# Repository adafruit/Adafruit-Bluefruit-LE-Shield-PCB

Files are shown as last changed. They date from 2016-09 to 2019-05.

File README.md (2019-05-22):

## Adafruit Bluefruit LE Shield PCB
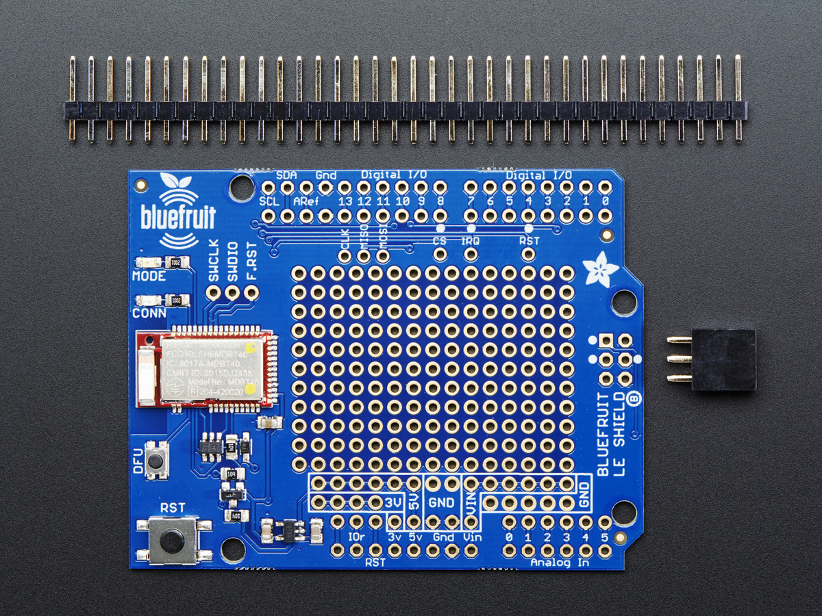
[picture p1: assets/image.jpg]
<a href="http://www.adafruit.com/products/2746"><br/>
Click here to purchase one from the Adafruit shop</a>

Would you like to add powerful and easy-to-use Bluetooth Low Energy to your robot, art or other electronics project? Heck yeah! With BLE now included in modern smart phones and tablets, its fun to add wireless connectivity. So what you really need is the new Adafruit Bluefruit LE Shield for Arduino!

The Bluefruit LE Shield makes it easy to add Bluetooth Low Energy connectivity to your Arduino or compatible.  Solder in the included headers and plug right in. It connects to your Arduino or other microcontroller using the hardware SPI interface (MISO, MOSI, SCK) plus a chip select line (default D8), interrupt line (default D7) and reset (default D4). You can rearrange any and all the pins if you'd like, by cutting the jumpers underneath, and soldering jumper wires to your desired pins.

PCB files for the Adafruit Bluefruit LE Shield. The format is EagleCAD schematic and board layout
- https://www.adafruit.com/product/2746

### License

Adafruit invests time and resources providing this open source design, please support Adafruit and open-source hardware by purchasing products from [Adafruit](https://www.adafruit.com)!

All text above must be included in any redistribution

Designed by Limor Fried/Ladyada for Adafruit Industries.
Creative Commons Attribution/Share-Alike, all text above must be included in any redistribution. 
See license.txt for additional information.

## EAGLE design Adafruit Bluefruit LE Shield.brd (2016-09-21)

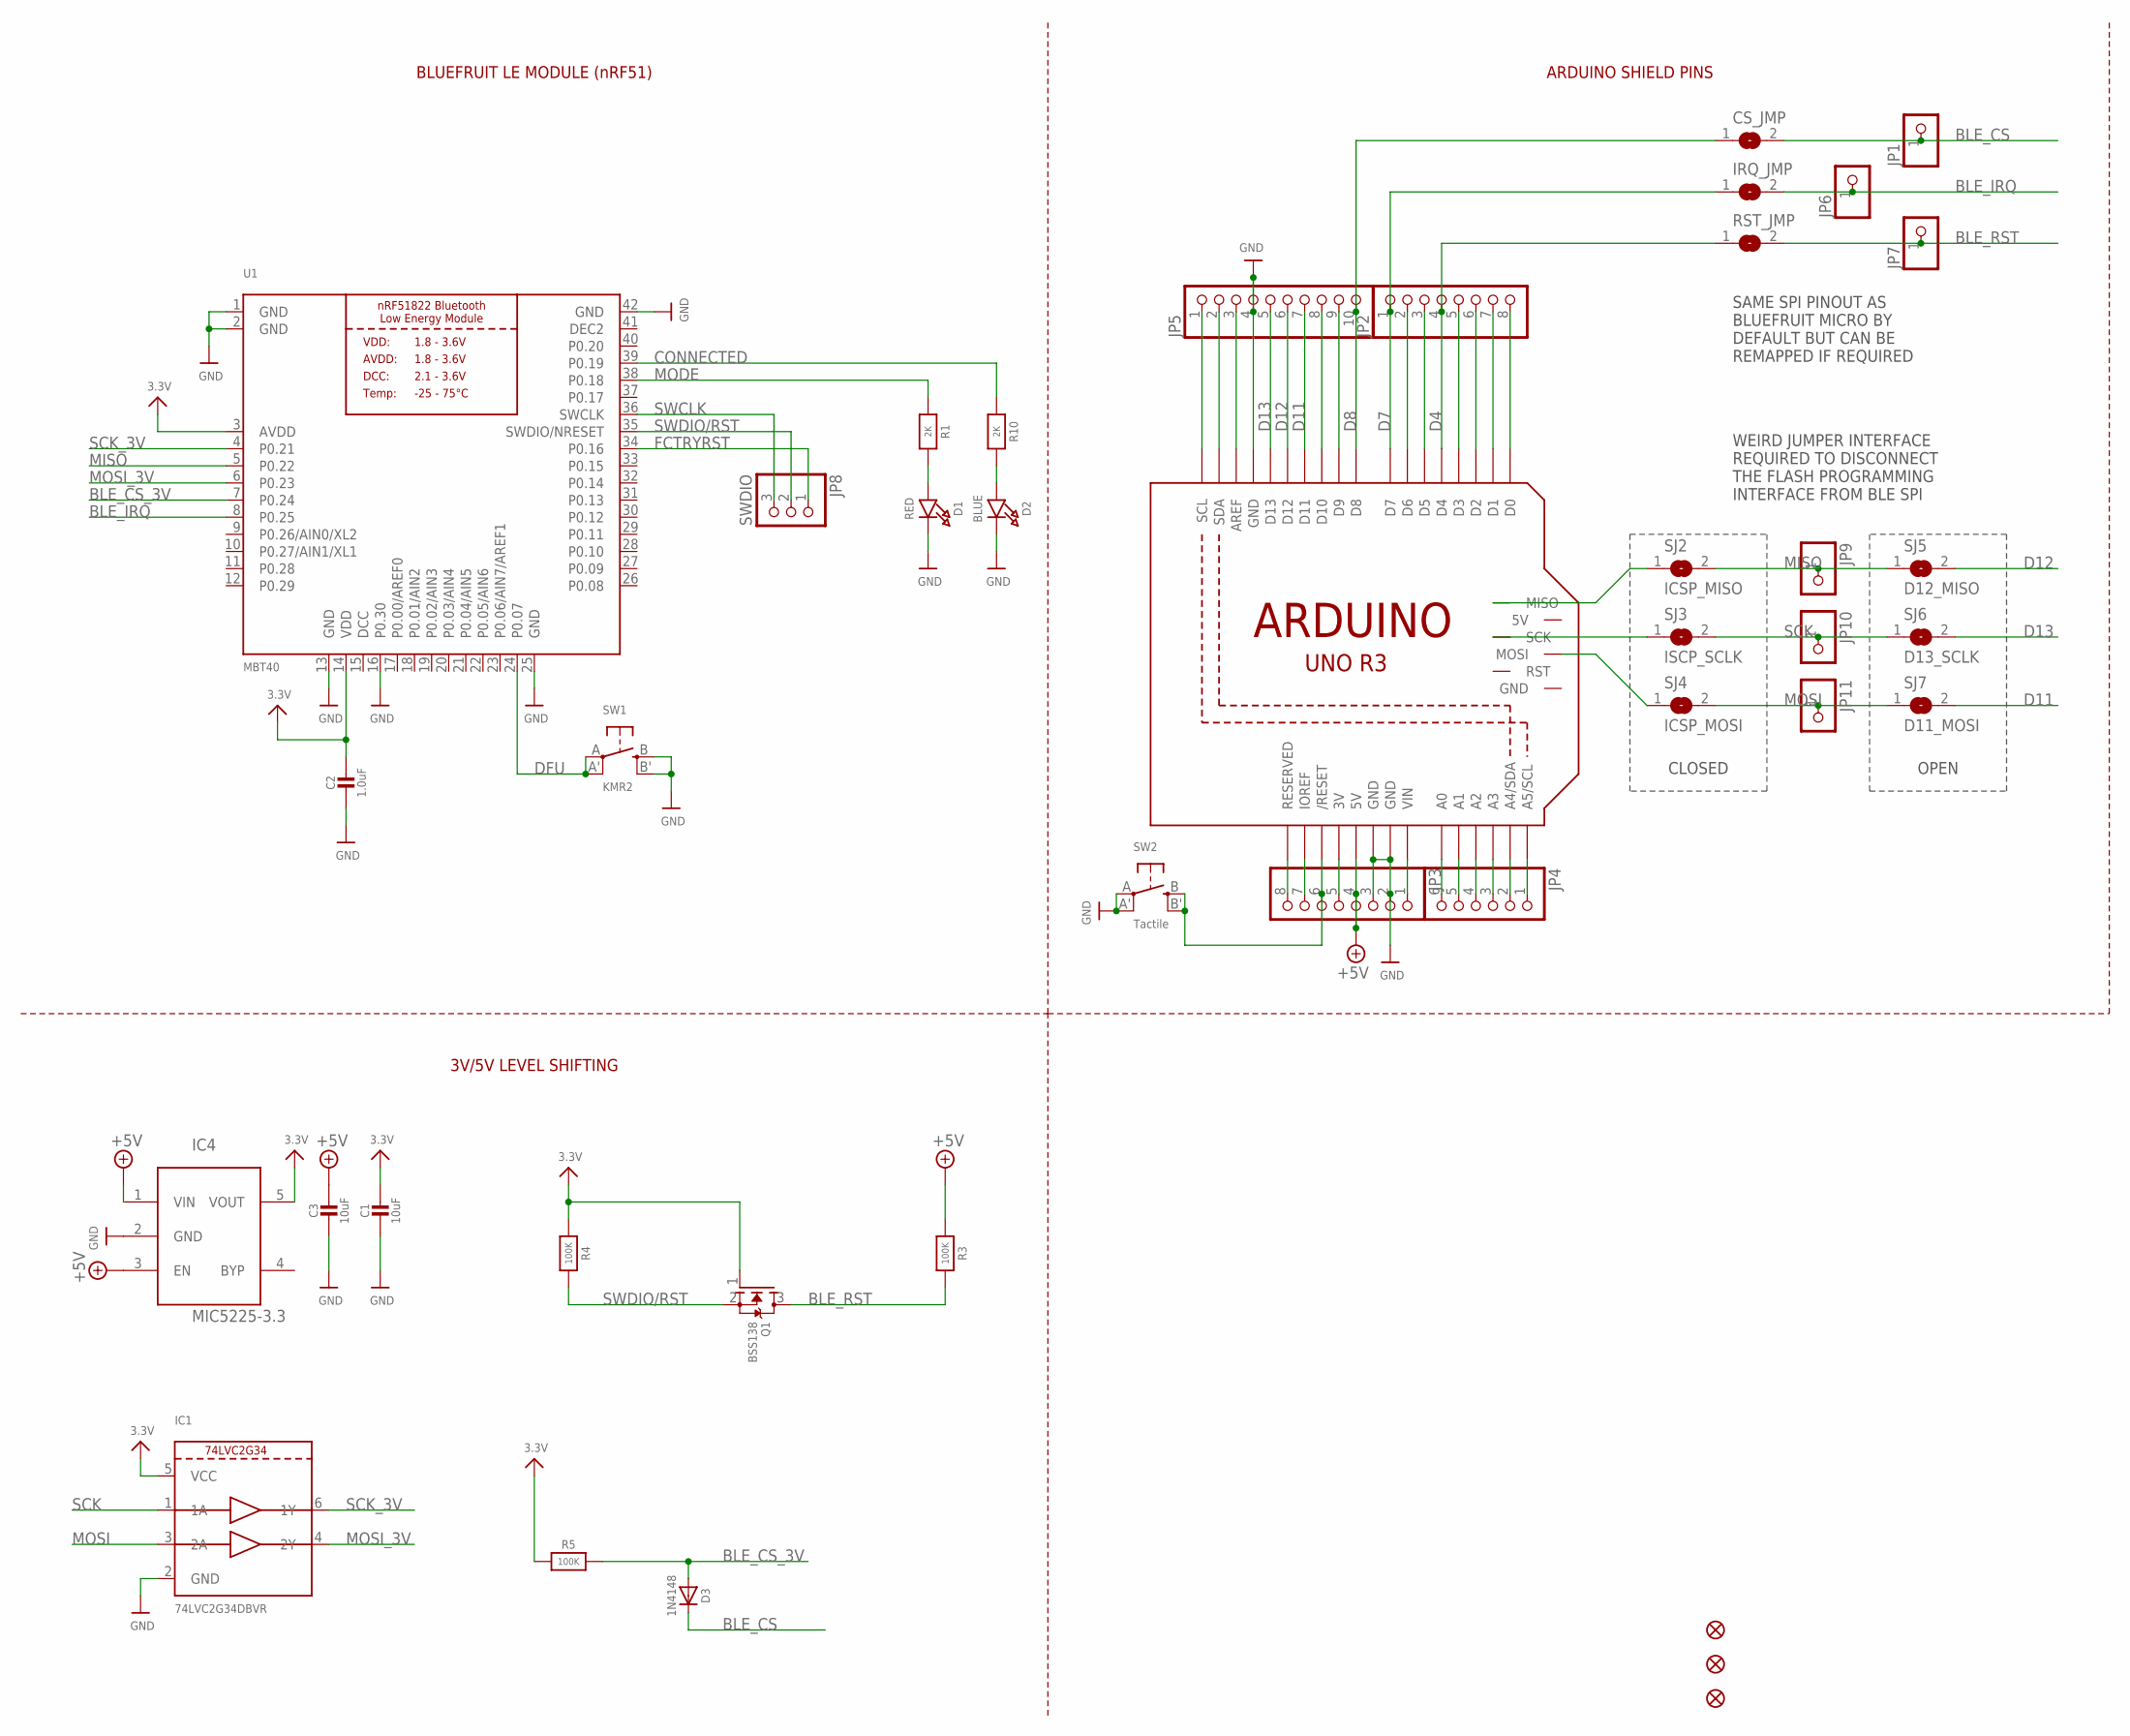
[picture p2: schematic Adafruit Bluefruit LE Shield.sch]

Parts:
C1, C3: 10uF; 0805-NO
C2: 1.0uF; 0805-NO
CS_JMP: SOLDERJUMPERCLOSED; SOLDERJUMPER_CLOSEDWIRE
D1: RED; CHIPLED_0805_NOOUTLINE
D2: BLUE; CHIPLED_0805_NOOUTLINE
D3: 1N4148; SOD-323
FID1, FID2, FID3: FIDUCIAL""; FIDUCIAL_1MM
IC1: 74LVC2G34DBVR; SOT23-6
IC4: MIC5225-3.3; SOT23-5L
IRQ_JMP: SOLDERJUMPERCLOSED; SOLDERJUMPER_CLOSEDWIRE
JP1, JP6, JP7, JP9, JP10, JP11: HEADER-1X1ROUND; 1X01_ROUND
JP2, JP3: HEADER-1X870MIL; 1X08_ROUND_70
JP4: HEADER-1X670MIL; 1X06_ROUND_70
JP5: HEADER-1X1070MIL; 1X10_ROUND70
JP8: SWDIO; 1X03_ROUND_76
M1: ARDUINO_R3_ICSP_NODIM; ARDUINOR3_ICSP_NODIM
Q1: BSS138; SOT23-WIDE
R1, R10: 2K; 0805-NO
R3, R4, R5: 100K; 0805-NO
RST_JMP: SOLDERJUMPERCLOSED; SOLDERJUMPER_CLOSEDWIRE
SJ2: ICSP_MISO; SOLDERJUMPER_CLOSEDWIRE
SJ3: ISCP_SCLK; SOLDERJUMPER_CLOSEDWIRE
SJ4: ICSP_MOSI; SOLDERJUMPER_CLOSEDWIRE
SJ5: D12_MISO; SOLDERJUMPER_REFLOW_NOPASTE
SJ6: D13_SCLK; SOLDERJUMPER_REFLOW_NOPASTE
SJ7: D11_MOSI; SOLDERJUMPER_REFLOW_NOPASTE
SW1: KMR2; BTN_KMR2_4.6X2.8
SW2: Tactile; EVQ-Q2
U1: MBT40; BLE_MODULE_RAYTAC_MDBT40

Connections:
3.3V: C1.1, C2.1, IC1.5 (VCC), IC4.5 (VOUT), Q1.1 (G), R4.1, R5.1, U1.3 (AVDD), U1.14 (VDD)
+3V: JP3.5, M1.3V
+5V: C3.1, IC4.1 (VIN), IC4.3 (EN), JP3.4, M1.5V, R3.1
A0: JP4.6, M1.A0
A1: JP4.5, M1.A1
A2: JP4.4, M1.A2
A3: JP4.3, M1.A3
A4: JP4.2, M1.A4 (A4/SDA)
A5: JP4.1, M1.A5 (A5/SCL)
AREF: JP5.3, M1.AREF
BLE_CS: CS_JMP.2, D3.C, JP1.1
BLE_CS_3V: D3.A, R5.2, U1.7 (P0.24)
BLE_IRQ: IRQ_JMP.2, JP6.1, U1.8 (P0.25)
BLE_RST: JP7.1, Q1.3 (D), R3.2, RST_JMP.2
CONNECTED: R10.1, U1.39 (P0.19)
D4: JP2.4, M1.D4, RST_JMP.1
D7: IRQ_JMP.1, JP2.1, M1.D7
D8: CS_JMP.1, JP5.10, M1.D8
D11: JP5.7, M1.D11, SJ7.2
D12: JP5.6, M1.D12, SJ5.2
D13: JP5.5, M1.D13, SJ6.2
DCC: U1.15 (DCC)
DEC2: U1.41 (DEC2)
DFU: SW1.A, SW1.A' (P1), U1.24 (P0.07)
FCTRYRST: JP8.1, U1.34 (P0.16)
GND: C1.2, C2.2, C3.2, D1.C, D2.C, IC1.2 (GND), IC4.2 (GND), JP3.2, JP3.3, JP5.4, M1.GND, M1.GND@1 (GND), M1.GND@3 (GND), SW1.B (S), SW1.B' (S1), SW2.A, SW2.A' (P1), U1.1 (GND), U1.2 (GND), U1.13 (GND), U1.16 (P0.30), U1.25 (GND), U1.42 (GND)
IOREF: JP3.7, M1.IOREF
MISO: JP9.1, SJ2.2, SJ5.1, U1.5 (P0.22)
MISO_ICSP: M1.MISO, SJ2.1
MODE: R1.1, U1.38 (P0.18)
MOSI: IC1.3 (2A), JP11.1, SJ4.2, SJ7.1
MOSI_3V: IC1.4 (2Y), U1.6 (P0.23)
MOSI_ICSP: M1.MOSI, SJ4.1
unnamed: D1.A, R1.2
unnamed: D2.A, R10.2
unnamed: JP2.2, M1.D6
unnamed: JP2.3, M1.D5
unnamed: JP2.5, M1.D3
unnamed: JP2.6, M1.D2
unnamed: JP2.7, M1.D1
unnamed: JP2.8, M1.D0
unnamed: JP5.8, M1.D10
unnamed: JP5.9, M1.D9
NC: JP3.8, M1.RESERVED
RESET: JP3.6, M1.RESET (/RESET), SW2.B (S), SW2.B' (S1)
SCK: IC1.1 (1A), JP10.1, SJ3.2, SJ6.1
SCK_3V: IC1.6 (1Y), U1.4 (P0.21)
SCK_ICSP: M1.SCK, SJ3.1
SCL: JP5.1, M1.SCL
SDA: JP5.2, M1.SDA
SWCLK: JP8.3, U1.36 (SWCLK)
SWDIO/RST: JP8.2, Q1.2 (S), R4.2, U1.35 (SWDIO/NRESET)
VIN: JP3.1, M1.VIN

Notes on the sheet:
ARDUINO SHIELD PINS
BLUEFRUIT LE MODULE (nRF51)
WEIRD JUMPER INTERFACE REQUIRED TO DISCONNECT THE FLASH PROGRAMMING INTERFACE FROM BLE SPI
CLOSED
OPEN
3V/5V LEVEL SHIFTING
SAME SPI PINOUT AS BLUEFRUIT MICRO BY DEFAULT BUT CAN BE REMAPPED IF REQUIRED

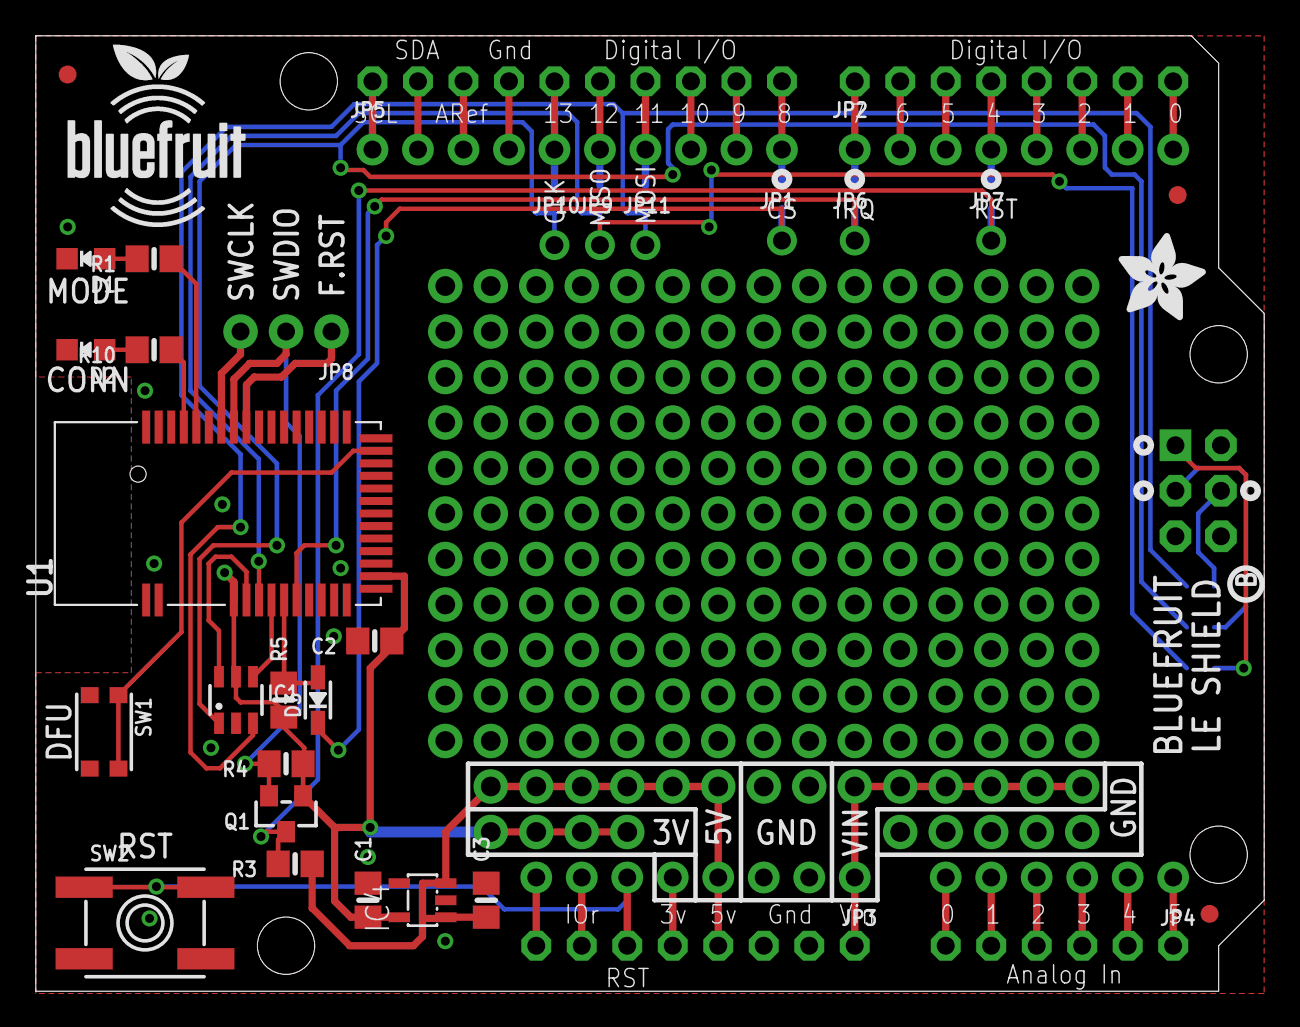
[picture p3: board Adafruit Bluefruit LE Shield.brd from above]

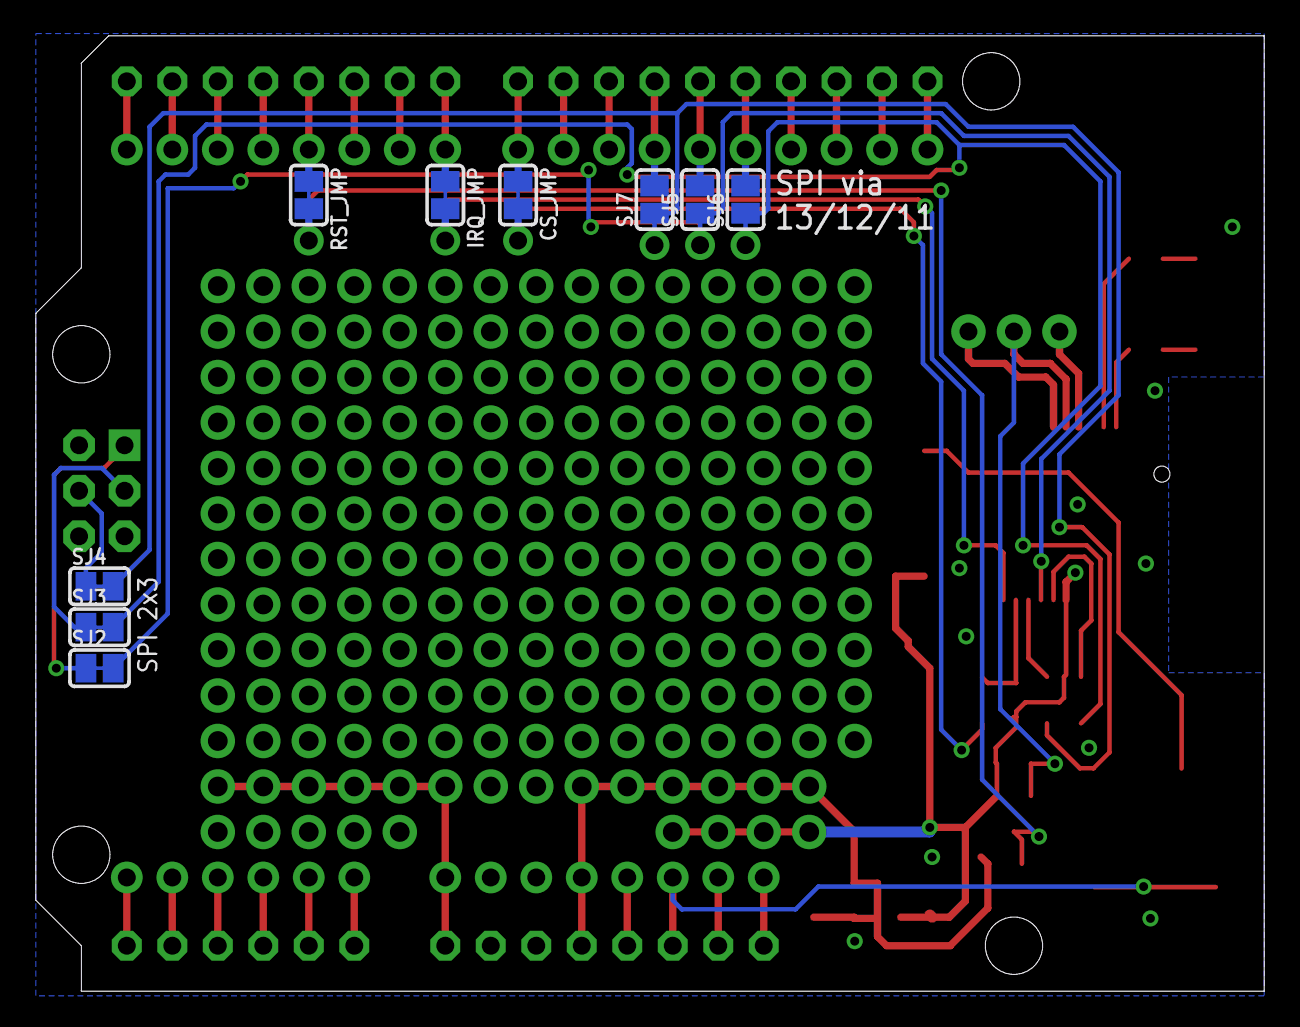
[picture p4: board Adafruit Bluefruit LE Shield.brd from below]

Board: 2 copper layers, 68.6 x 53.3 mm, 44 parts (9 on the bottom side), 51 nets.

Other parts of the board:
U$8: BLUEFRUITLOGO_100MM
U$9: ADAFRUIT_5MM
U$21: PCBFEAT-REV-040

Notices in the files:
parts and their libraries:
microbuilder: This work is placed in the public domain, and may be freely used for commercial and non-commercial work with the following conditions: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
